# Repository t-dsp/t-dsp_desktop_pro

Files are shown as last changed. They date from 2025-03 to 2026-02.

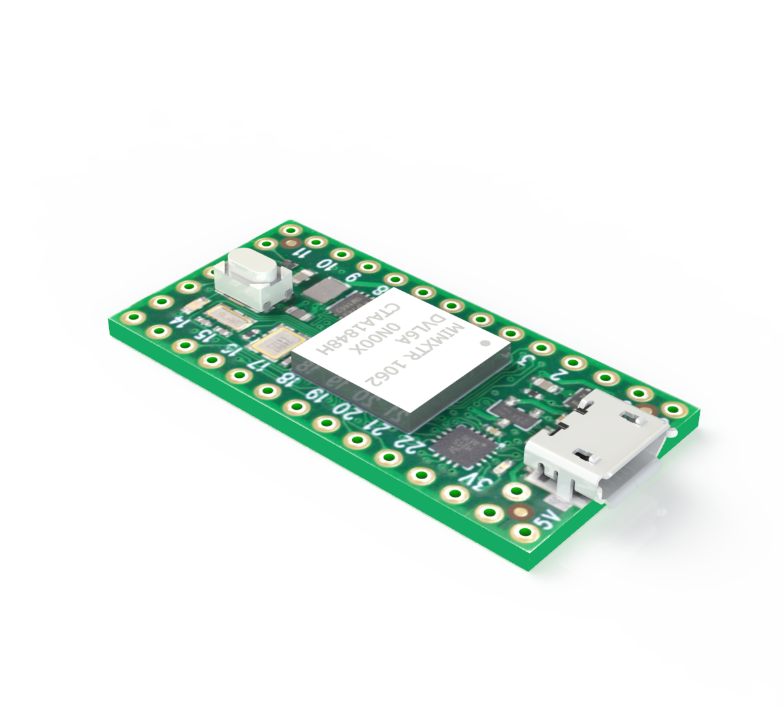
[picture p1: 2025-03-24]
3d_models/teensy-4-0-1.snapshot.3/Teensy_4.0/Renders/Teensy_4.0.png

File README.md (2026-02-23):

# T-DSP Desktop Pro

**Part of the [T-DSP](https://t-dsp.com) open modular audio platform.**

A desktop audio backplane (120mm x 100mm) that serves as the central hub for the T-DSP modular audio ecosystem. Hosts a Teensy 4.1, ESP32, and T-DSP TAC5212 pro audio codec module on an 8-layer PCB designed for studio-quality signal integrity.

T-DSP Desktop Pro - Top Isometric

| | |
|:---:|:---:|
| Top | Bottom |
| Front | Rear |

**[View 3D Render Gallery](https://t-dsp.github.io/t-dsp_desktop_pro/gallery.html)** -- interactive slideshow of all board views

## About T-DSP

T-DSP is an open modular audio platform designed for musicians, engineers, and developers who want powerful digital signal processing in a flexible, hackable format. Built around the [Teensy](https://www.pjrc.com/teensy/) microcontroller and the [Teensy Audio Library](https://www.pjrc.com/teensy/td_libs_Audio.html), T-DSP combines studio-quality audio with a growing library of open-source modules for mixing, synthesis, effects, and more.

Whether you're building a custom digital mixer, crafting a unique instrument, or prototyping audio products, T-DSP gives you the tools to bring your ideas to life.

Join the community, contribute to the library, or grab a module and start patching. Learn more at [t-dsp.com](https://t-dsp.com).

## Overview

The Desktop Pro is a **backplane PCB** that hosts a Teensy 4.1, ESP32, and T-DSP codec module alongside supporting ICs to create a complete audio development platform. It provides all the connectors, processing, networking, and user interface needed to build desktop audio devices.

## Processing

- **Teensy 4.1** -- ARM Cortex-M7 running the Teensy Audio Library for real-time audio processing (mixing, effects, synthesis, routing). Also receives USB Audio.
- **ESP32** -- UI controller, WiFi/Bluetooth connectivity. Runs the display, buttons, and encoder, and sends commands to the Teensy over serial.
- **T-DSP TAC5212 Module** -- Professional stereo audio codec (ADC + DAC) with mic preamp, line, and instrument inputs

## On-Board ICs

| Ref | Part | Function |
|-----|---|---|
| U1 | Teensy 4.1 | Audio DSP (ARM Cortex-M7) |
| U2 | ESP32-DevKitC | UI controller, WiFi/Bluetooth |
| U3 | TPS2116DRL | Power multiplexer (dual input selection) |
| U4 | H11L1SM | Optoisolator (MIDI input) |
| U5-U8 | SN74LVC2G125DCTR | Dual bus buffers (4x) |
| U9 | 74HCT2G17GW | Dual Schmitt trigger buffer |
| U10 | TPD4E02B04DQA | USB ESD protection (4-channel) |
| IC1 | 74HCT2G125DC | Logic level shifter |
| D5 | TPD1E10B06DPYT | VBUS ESD protection |
| Q1, Q2 | DMG2307L-7 | P-FET reverse polarity protection |

## Connectivity

### Audio I/O
- **RCA outputs** -- Stereo analog audio output
- **RCA inputs** -- Stereo analog audio input
- **Headphone output** -- 1/4" (6.35mm) or 3.5mm headphone jack
- **S/PDIF** -- Digital audio input and output

### USB
- **USB-C DEVICE** -- Power and USB Audio to Teensy with ESD protection (TPD4E02B04 + TPD1E10B06)
- **USB-A HOST** -- USB host connector

### MIDI
- **MIDI input** -- 3.5mm TRS with optical isolation (H11L1)
- **MIDI GPIO** -- Configurable for MIDI in, out, or thru

### Power
- **Dual power input** -- USB-C or external supply via JST-XH header, with TPS2116 power multiplexer for automatic switchover
- **Reverse polarity protection** -- P-channel MOSFET (DMG2307L-7) on both 5V and 12V inputs
- **Power indicators** -- LED indicators for 5V and 12V rails

### Storage
- **SD card** -- Accessible via Teensy 4.1 built-in SD slot

## Expansion

- **2x TDM expansion headers** (2x10 pin, 2.54mm) -- Connect T-DSP audio modules
  - TDM digital audio bus (BCLK, LRCK, DATA_IN, DATA_OUT, MCLK)
  - I2C control bus (SDA, SCL)
  - Power rails (3.3V, 5V, 12V, GND)
  - Control pins (Held-high, Held-low)
- Modules can be soldered directly or socketed with pin headers
- Multiple modules can be chained on the same TDM bus

## User Interface

The backplane exposes interface-ready GPIO headers for flexible UI connectivity, supporting popular interface options compatible with the ESP32.

- **GPIO header** -- Active-low buttons, rotary encoder, and display connections for tactile UI
- **OLED display header** (128x64, SSD1306) -- Status and menu-driven UI
- **3.2" TFT touchscreen header** (ILI9341) -- Touchscreen UI
- **SK6812 addressable LED header** -- ESP32 and Teensy status indication, plus LED strip control

## Board Design

- **8-layer PCB** with dedicated ground and power planes for low-noise analog performance
- **120mm x 100mm** board dimensions
- LDO voltage regulation for clean analog power
- Buffered digital outputs for reliable module distribution
- Separate analog and digital ground domains

## Project Files

| Directory | Contents |
|---|---|
| `/3d_models/` | 3D models for PCB components |
| `/documentation/` | [Schematic PDF](documentation/t-dsp-desktop-pro-schematic.pdf), board images, and reference docs |
| `/lib_fp/` | Custom KiCad footprint libraries |
| `/lib_sch/` | Custom KiCad schematic symbol libraries |
| `/manufacturing/` | CI-generated manufacturing outputs (gerbers, BOM, pick & place, PDFs) |
| `/panel/` | Panelized board layouts for production |
| `/pages/` | [3D Render Gallery](https://t-dsp.github.io/t-dsp_desktop_pro/gallery.html), [Interactive BOM](https://t-dsp.github.io/t-dsp_desktop_pro/ibom.html) |

View the design files directly in your browser with KiCanvas: [Schematic](https://kicanvas.org/?github=https://github.com/t-dsp/t-dsp_desktop_pro/blob/main/t-dsp_desktop_pro.kicad_sch) | [PCB](https://kicanvas.org/?github=https://github.com/t-dsp/t-dsp_desktop_pro/blob/main/t-dsp_desktop_pro.kicad_pcb)

## Status

This board is under active development. The current revision includes USB-C ESD protection, reverse polarity protection, and boot pin corrections from the pre-production review.

If you build one, we'd love to hear how it goes -- please open an issue or reach out with your findings.

## Contact

For consulting, custom backplane design, or commercial licensing inquiries, reach out via [LinkedIn](https://linkedin.com/in/jayshoe).

## License

This project is licensed under the [Creative Commons Attribution-NonCommercial-ShareAlike 4.0 International (CC BY-NC-SA 4.0)](https://creativecommons.org/licenses/by-nc-sa/4.0/).

You are free to share and adapt this work for non-commercial purposes, as long as you give appropriate credit and distribute any derivatives under the same license.

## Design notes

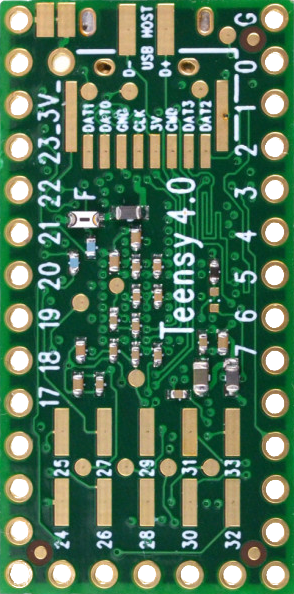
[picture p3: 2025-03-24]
3d_models/teensy-4-0-1.snapshot.3/Teensy_4.0/Teensy_4.0_Decal/Teensy_4.0_Back.png

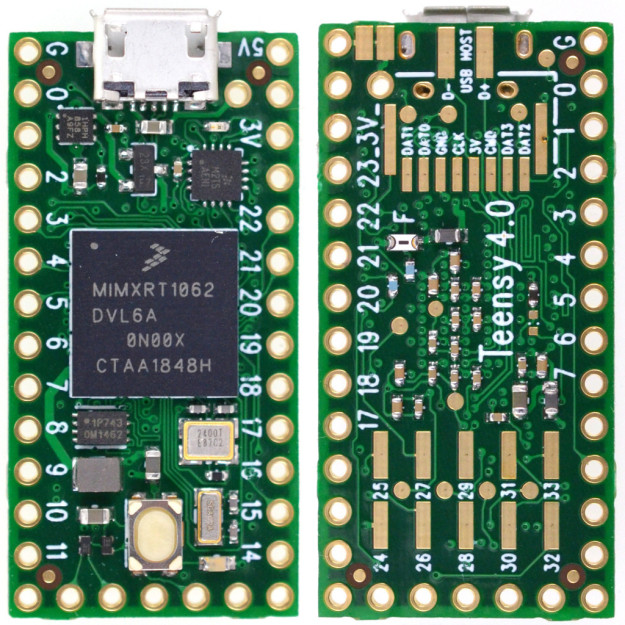
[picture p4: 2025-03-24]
3d_models/teensy-4-0-1.snapshot.3/Teensy_4.0/Teensy_4.0_Decal/teensy40-launch-frontandback-thumb.jpg

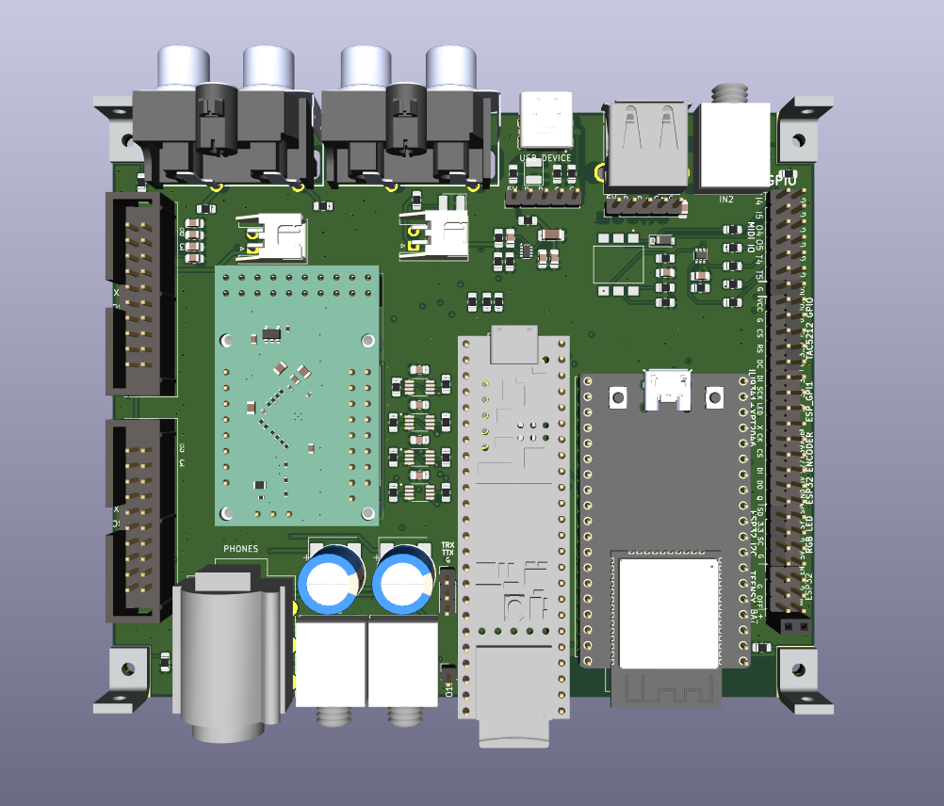
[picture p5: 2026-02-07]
documentation/t-dsp-desktop-pro-3d-top.png

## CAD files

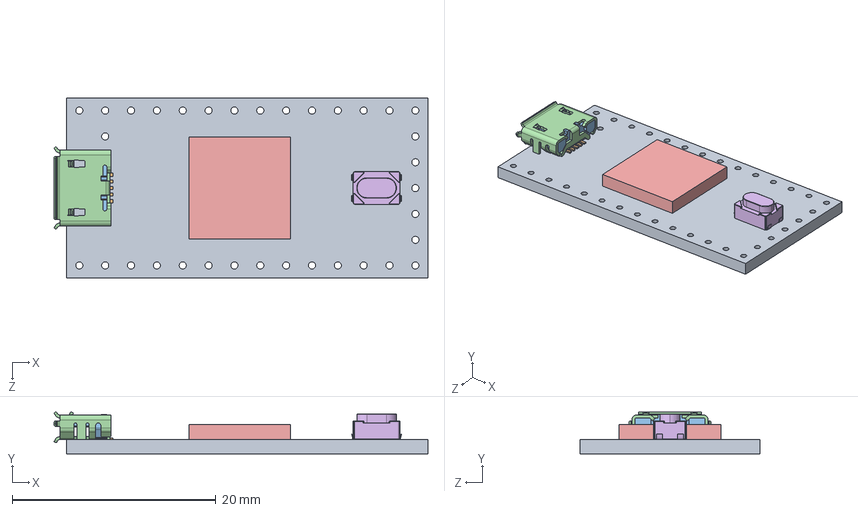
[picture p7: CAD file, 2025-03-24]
3d_models/teensy-4-0-1.snapshot.3/Teensy_4.0/Teensy_4.0_Assembly.STEP
36.8 x 4.12 x 17.7 mm
Teensy_4.0_PCB
Micro USB-B Female 5Pin SMD
NXP iMXRT1062
SKRPACE010 v4

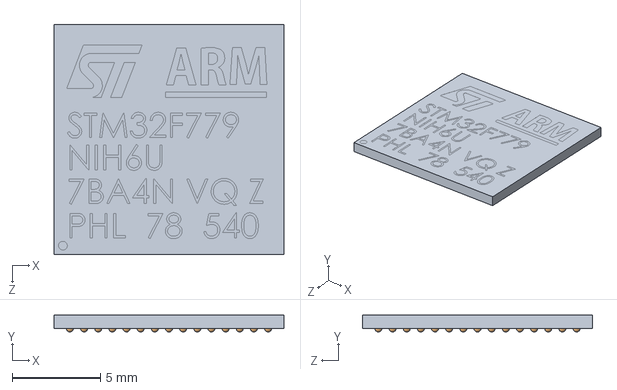
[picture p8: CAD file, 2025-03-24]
3d_models/teensy-4-0-1.snapshot.3/Teensy_4.0/STM32F779NIHx.SLDASM
13.0 x 0.96 x 13.0 mm
ball x 216

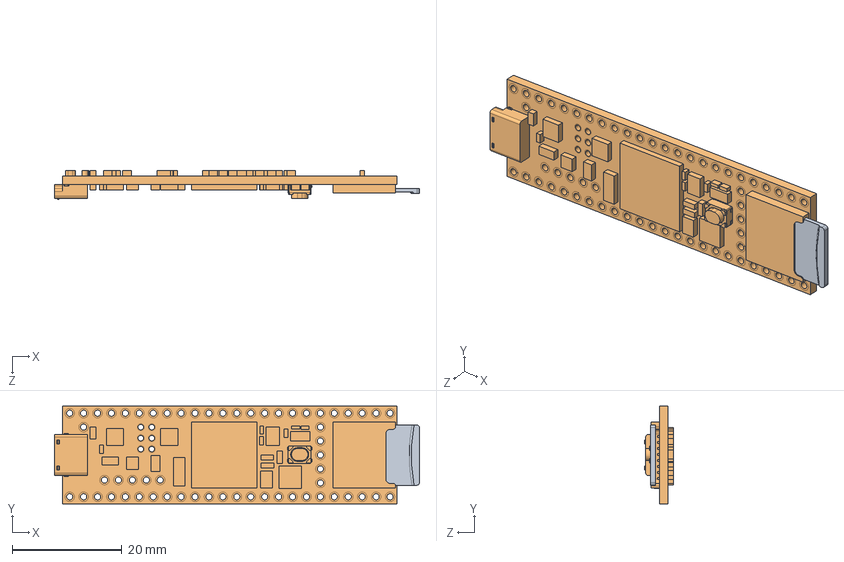
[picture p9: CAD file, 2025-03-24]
3d_models/Teensy_4.1_Assembly.STEP
66.6 x 17.8 x 5.27 mm

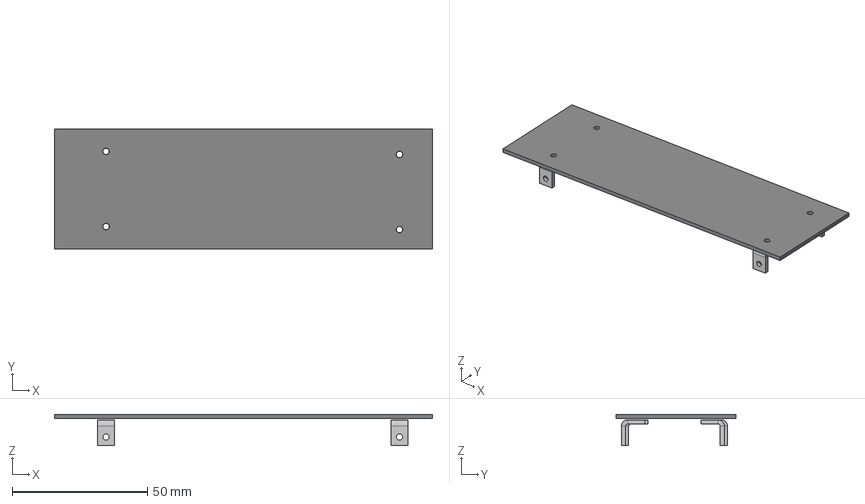
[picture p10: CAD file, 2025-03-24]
3d_models/audio_project_board_step/teensy41_audio_project_board_end2.step
139.7 x 44.5 x 11.5 mm
Pcb_76c7
H3_Bracket 4-40 621_9e0d8cd628db x 4

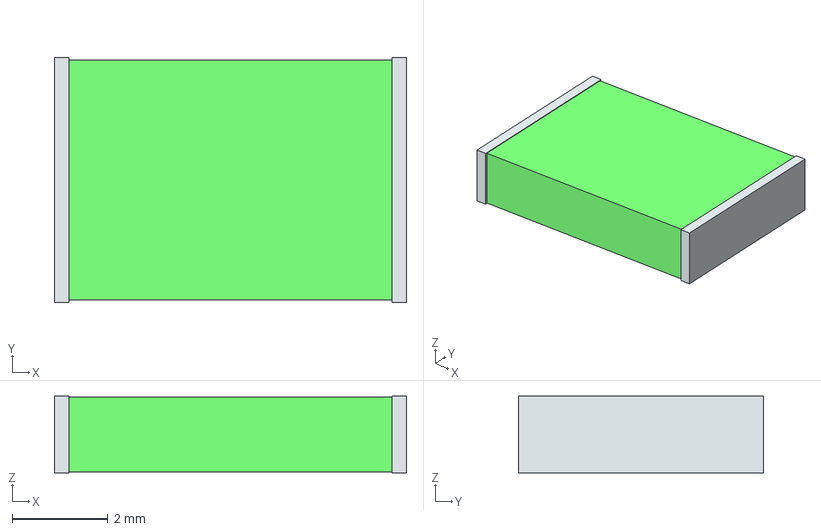
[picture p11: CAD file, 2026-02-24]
3d_models/MF-LSMF300_24X-2.stp
7.36 x 5.12 x 1.60 mm
term1
term2

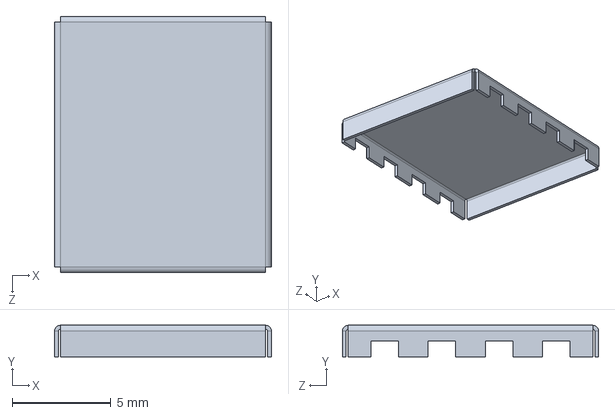
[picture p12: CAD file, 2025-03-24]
3d_models/raspberry-pi-4-model-b-1.snapshot.3/Cypress CYW43455 Wireless Module Cover, RPi4ModelB.SLDPRT
11.0 x 1.60 x 13.0 mm

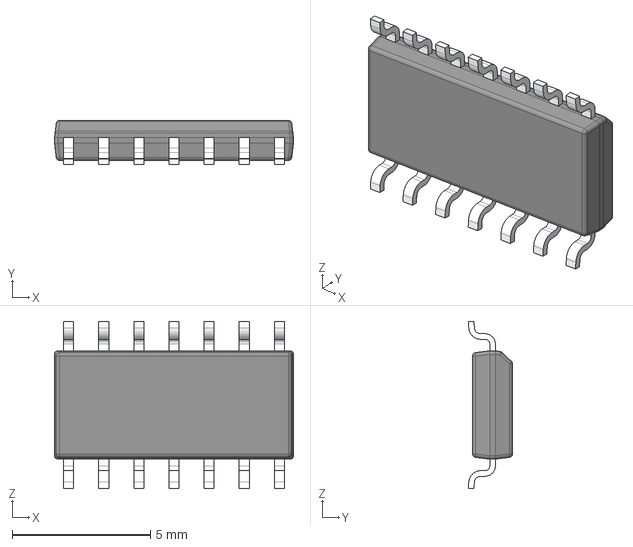
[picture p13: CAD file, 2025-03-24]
3d_models/so-14-soic14-1.snapshot.2/soic-14.stp
8.64 x 1.60 x 6.05 mm
BODY_M14A_20
LEAD_M14A_46 x 14

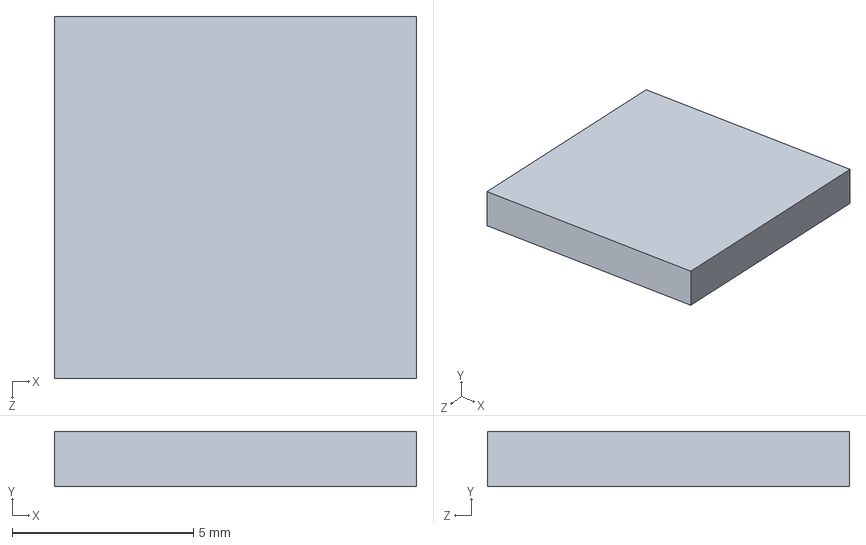
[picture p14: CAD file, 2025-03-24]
3d_models/teensy-4-0-1.snapshot.3/Teensy_4.0/NXP iMXRT1062.SLDPRT
10.0 x 1.52 x 10.0 mm

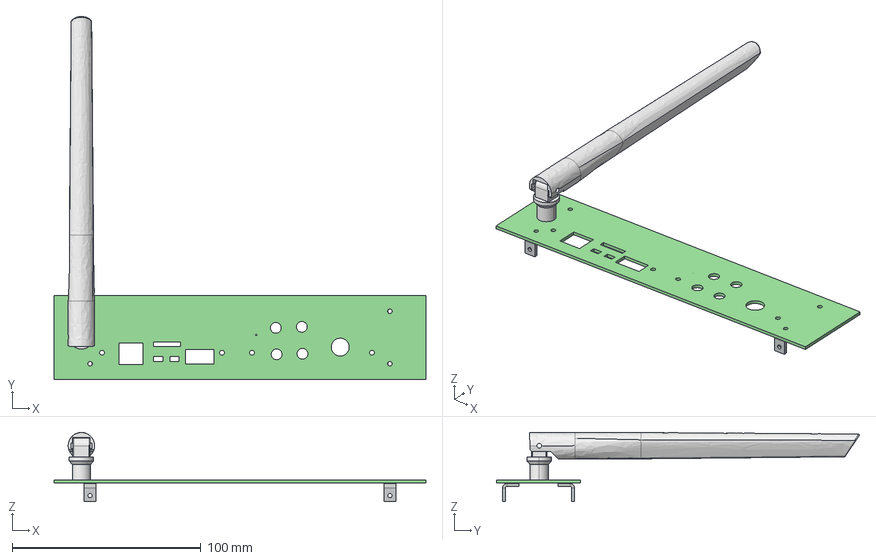
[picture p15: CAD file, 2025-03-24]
3d_models/audio_project_board_step/teensy41_audio_project_board_fp_c_front.step
196.8 x 192.2 x 36.6 mm
front_panel PCB

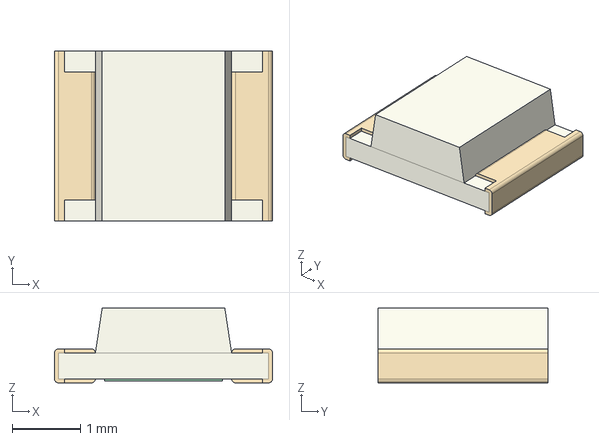
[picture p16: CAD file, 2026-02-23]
3d_models/LED_1210_3225Metric.step
3.20 x 2.50 x 1.10 mm

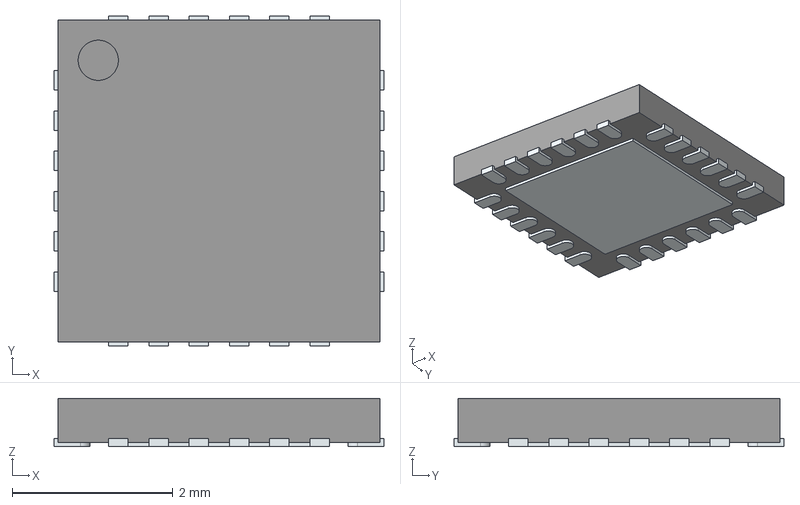
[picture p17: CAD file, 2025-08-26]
lib_fp/project_fp/CYPD3177-24LQXQ.stp
4.10 x 4.10 x 0.6 mm
ThermalPin
PinsArrayLR
PinsArrayTB

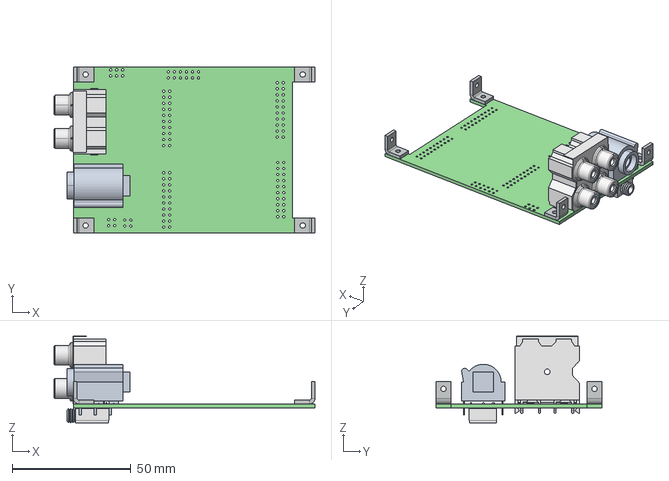
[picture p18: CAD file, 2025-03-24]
3d_models/audio_project_board_step/teensy41_audio_project_board_codec.step
109.8 x 69.8 x 36.5 mm
_autosave-teensy41_audio_project_board PCB

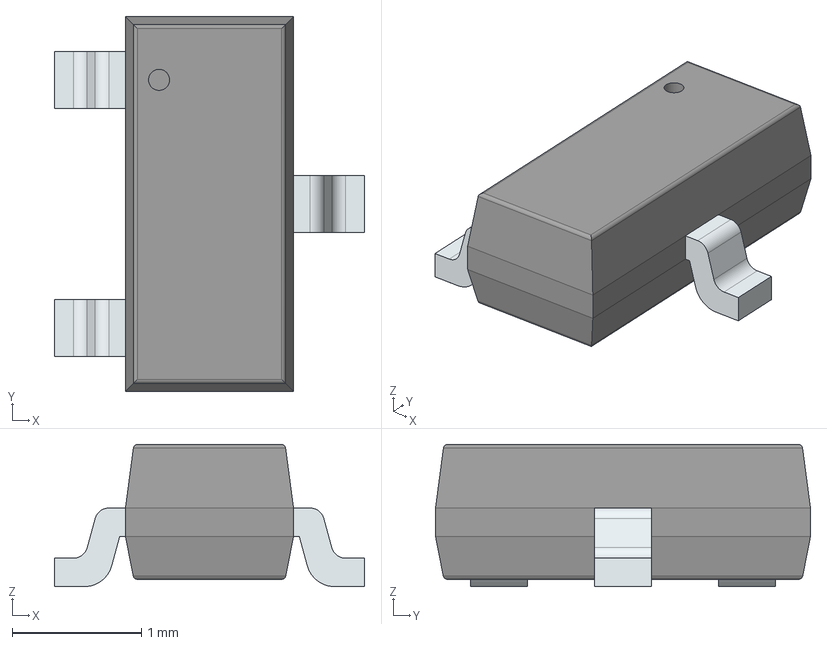
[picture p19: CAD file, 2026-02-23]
3d_models/DMG2307L-7.stp
2.40 x 2.90 x 1.10 mm
PinsArrayL
FilletPinR

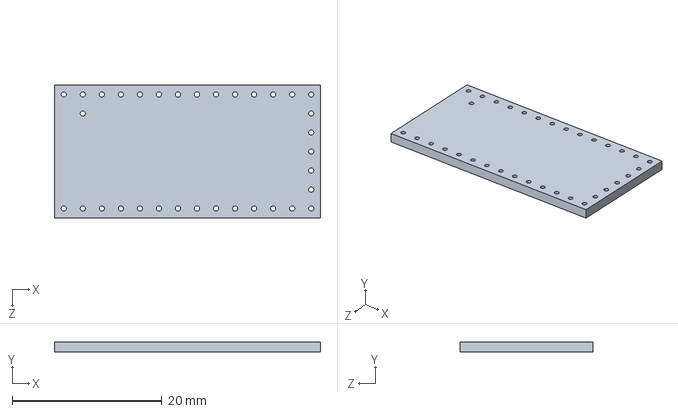
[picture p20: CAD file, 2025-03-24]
3d_models/teensy-4-0-1.snapshot.3/Teensy_4.0/Teensy_4.0_PCB.SLDPRT
35.5 x 1.40 x 17.7 mm

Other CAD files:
lib_fp/project_fp/TYPE-C-31-M-12.step
3d_models/1808--3DModel-STEP-630548.STEP
3d_models/2120--3DModel-STEP-630548.STEP
3d_models/3-D NC3MAH.stp
3d_models/3-D NCJ6FAH.stp
3d_models/3-D NCJ6FI-H-0.stp
3d_models/3-d-nmj6hcd3.stp
3d_models/3.5MM_STEREO_35RAPC4BHN2.STEP
3d_models/35RAPC3BH3.STEP
3d_models/35RAPC7JS.STEP
3d_models/35RAPC7JS_SIMPLIFIED.step
3d_models/3_2SPI-TFT-Modul_ILI9341.STEP
3d_models/4691.step
3d_models/74HCT2G125DC,125.stp
3d_models/74LS00.step
3d_models/Bracket 4-40 621.STEP
3d_models/COMBO-NCJ6FA-H.step
3d_models/COMBO_XLR_NCJ6FI-H-0.stp
3d_models/CP_Radial_D10.0mm_P5.00mm.step
3d_models/C_1206_3216Metric.step
3d_models/DC_BARREL_PJ-202AH.step
3d_models/DIN-5.STEP
3d_models/D_1210_3225Metric.step
3d_models/EN11-HSM1AF15.STEP
3d_models/ESP32 WROOMU.step
3d_models/ESP32-DEVKITC-32D.step
3d_models/ESP32-WROOM-32E.STEP
3d_models/ESP32-WROOM-32E_No-Cover.STEP
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

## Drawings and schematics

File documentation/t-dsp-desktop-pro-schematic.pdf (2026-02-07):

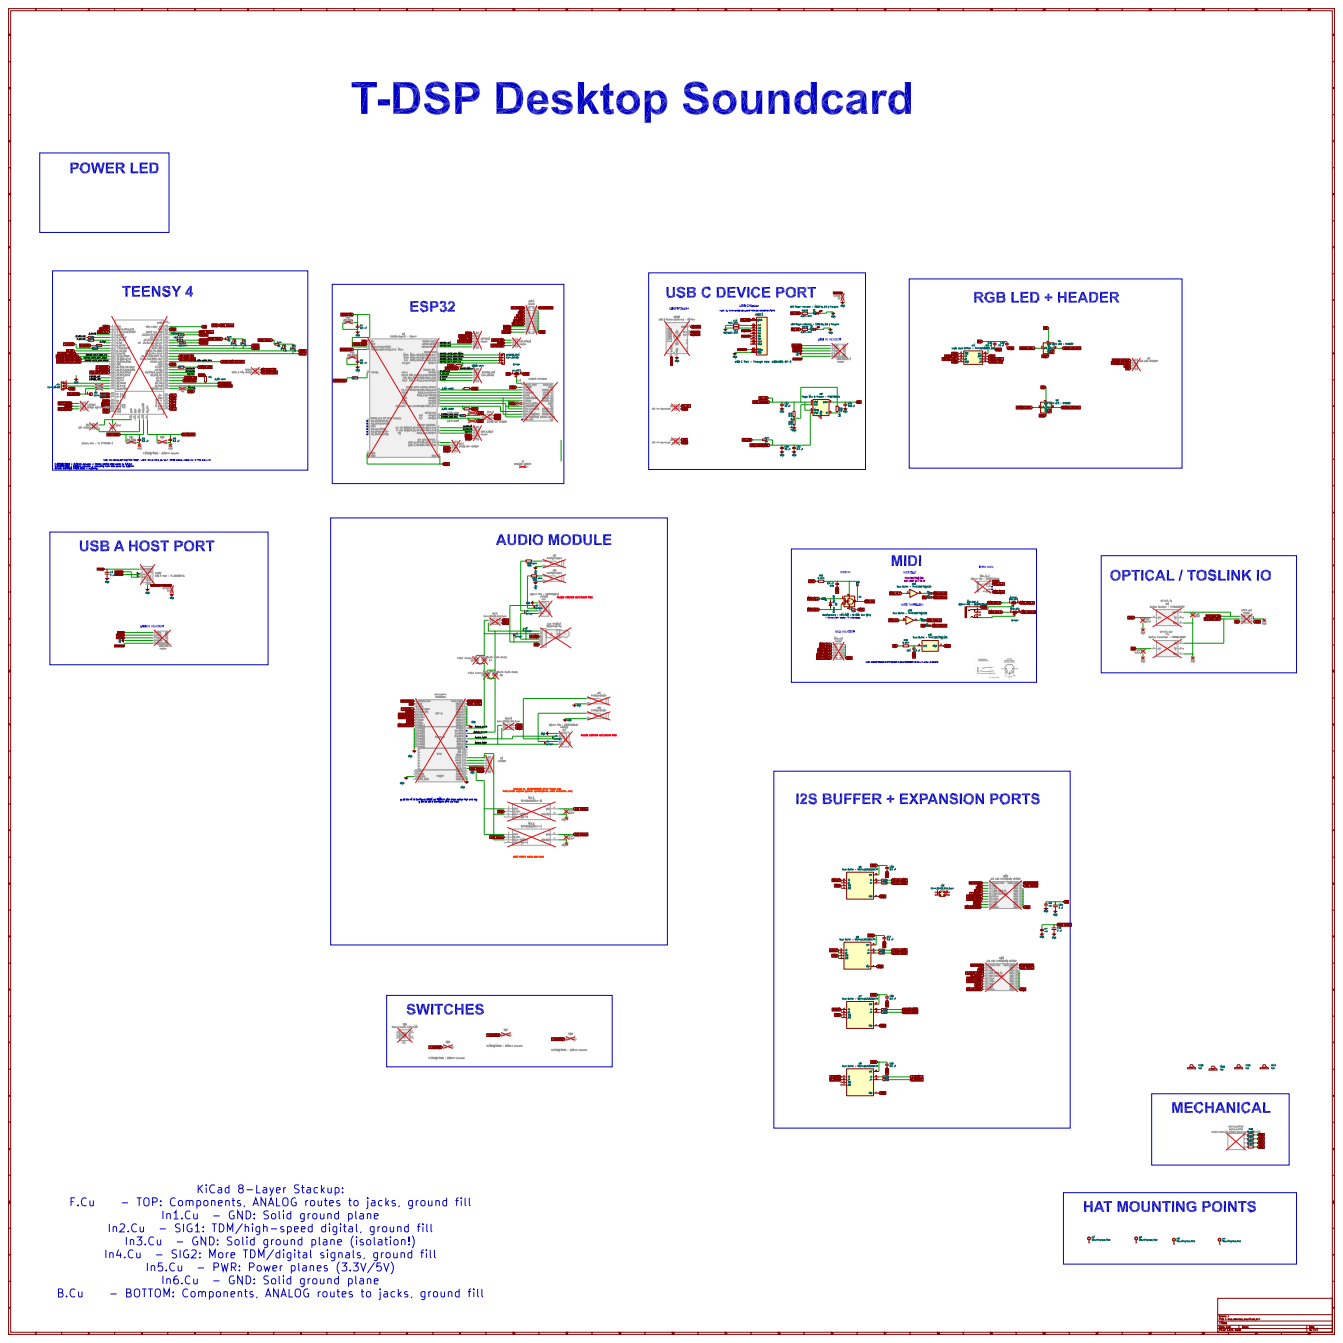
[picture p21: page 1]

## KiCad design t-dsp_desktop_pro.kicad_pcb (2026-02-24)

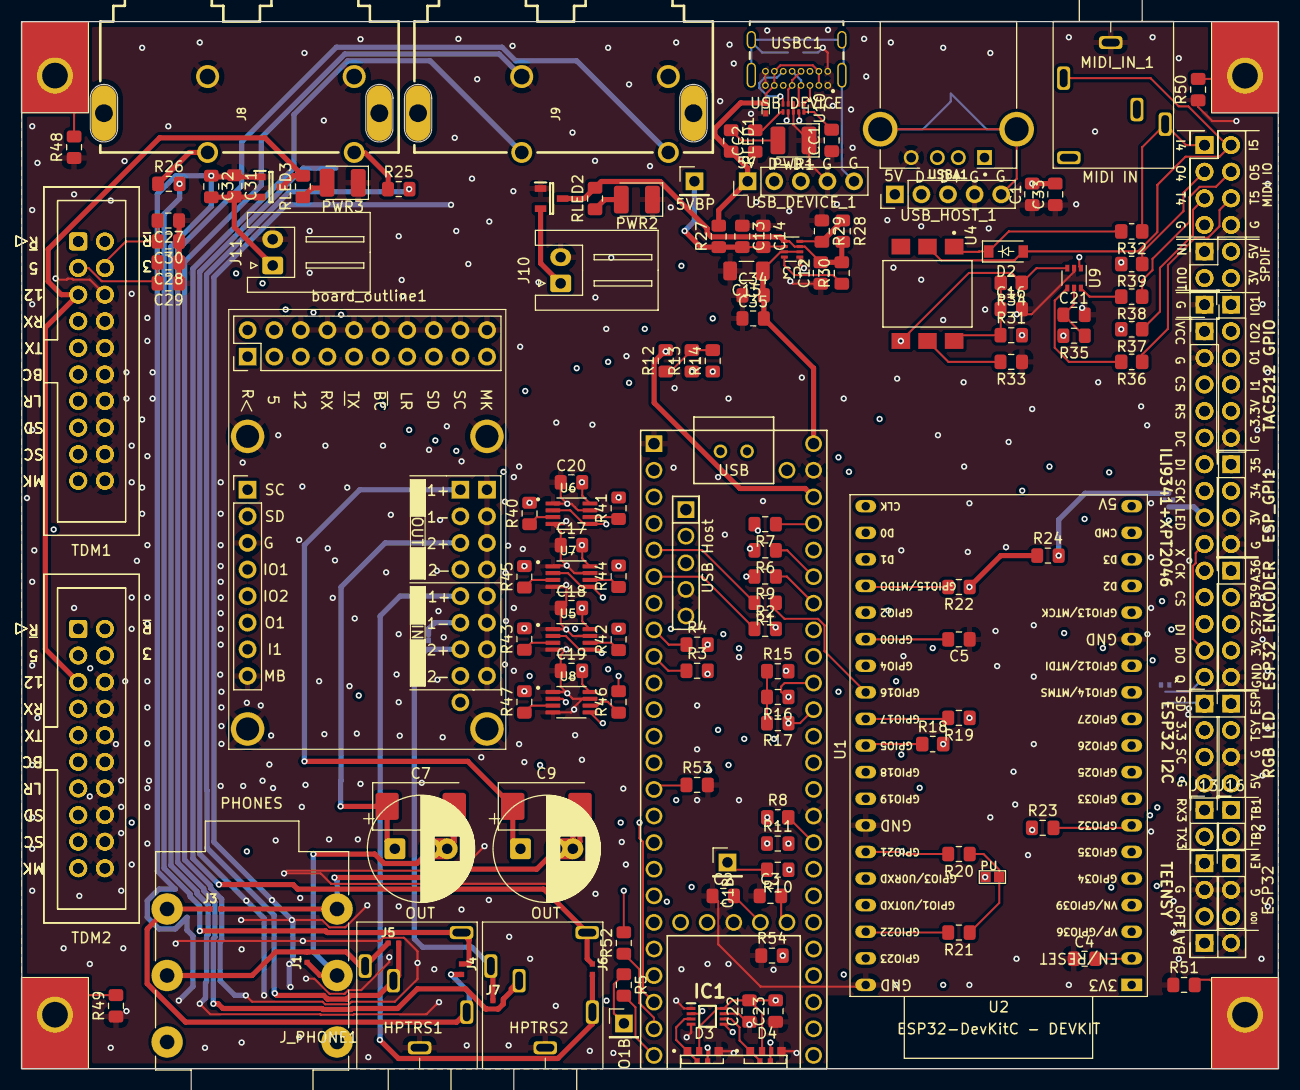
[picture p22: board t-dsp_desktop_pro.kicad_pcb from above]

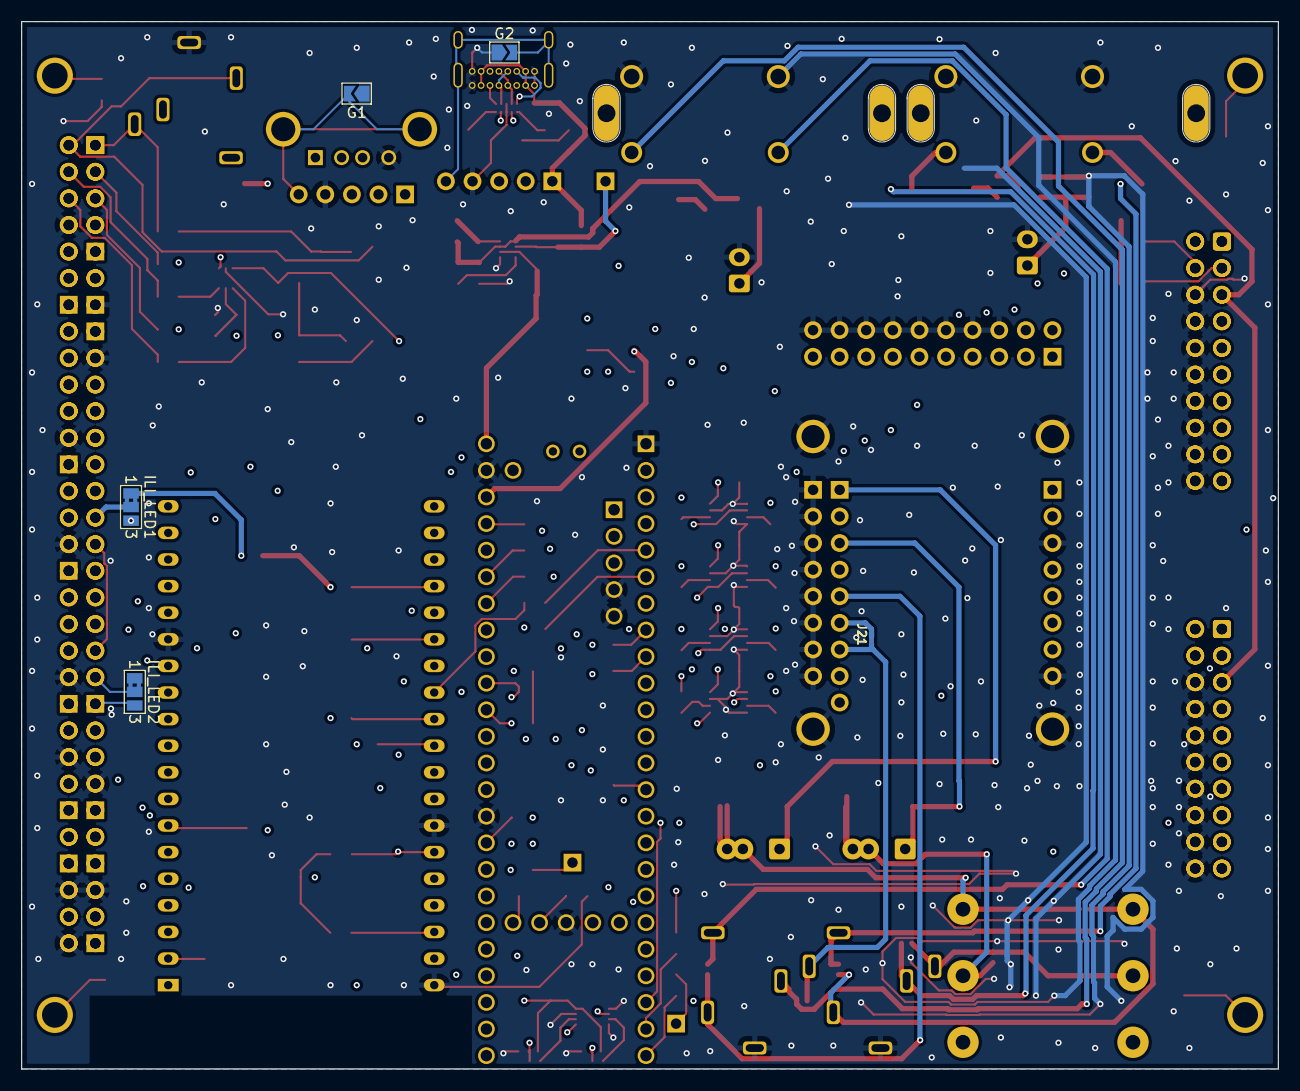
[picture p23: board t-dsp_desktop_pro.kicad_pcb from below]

Board: 8 copper layers, 120.0 x 100.0 mm, 156 parts (5 on the bottom side), 154 nets.

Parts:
BAT1: BAT HEADER; PinHeader_1x02_P2.54mm_Vertical_BAT
C1, C29, C30: 1 uF; C_0805_2012Metric_Pad1.15x1.40mm_HandSolder
C2, C3, C4, C5, C14, C16, C17, C18, C19, C20, C21, C22, C32, C35: 0.1 uF; C_0805_2012Metric_Pad1.15x1.40mm_HandSolder
C7, C9: 470 uF Electrolytic Audio-Grade; CP_Radial_D10.0mm_P5.00mm_AND_D8.0mm_P3.5mm
C12, C13, C23, C31, C33, C34: 10 uF; C_0805_2012Metric_Pad1.15x1.40mm_HandSolder
C15: 100 uF; C_1206_3216Metric_Pad1.33x1.80mm_HandSolder
C27, C28: 47uF; C_0805_2012Metric_Pad1.15x1.40mm_HandSolder
CC1, CC2: 5.1k ohm; R_0805_2012Metric_Pad1.15x1.40mm_HandSolder
D1: HEADER; TAC5212 GPIO_PinHeader_1x06_P2.54mm_Vertical
D2: Diode - 1N4148; D_SOD-123
D3, D4: Side Light LED - SK6812; SK6812-32228SMD-Reverse-Mount_mod
D5: TPD1E10B06DPYT
ESP_I1: ESP32 I2C HEADER; ESP_I2C_PinHeader_1x04_P2.54mm_Vertical
ESP_PROG1: header; E_PROG1_PinHeader_1x03_P2.54mm_Vertical
ESP_R_ENC1: header; ESP_R_ENC0_PinHeader_1x05_P2.54mm_Vertical
G1, G2: jumper; SolderJumper-2_P1.3mm_Open_TrianglePad1.0x1.5mm
GPI1: ESP32 GPI HEADER; GPI1_PinHeader_1x04_P2.54mm_Vertical
HPTRS1, HPTRS2: 3.5mm TRS - 35RAPC3BH3; 35RAPC3BH3
IC1: Logic Level Shifter - 74HCT2G125DC,125; SOP50P310X100-8N
ILI1: ILI9341+XPT2046; ILI9341_PinHeader_1x14_P2.54mm_Vertical
ILI_LED1, ILI_LED2: jumper; SolderJumper-3_P1.3mm_Bridged2Bar12_Pad1.0x1.5mm_NumberLabe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
J1, J3, J4, J5, J6, J7: jumper; jumper_slice_disconnected
J2: GROUND HEADER; GPIO_GROUND_PinHeader_1x01_P2.54mm_Vertical
J8, J9: PJRAS2X1S01X; PJRAS2X1S01X_MOD2
J10, J11: JST-XH Connector; JST_XH_S2B-XH-A_1x02_P2.50mm_Horizontal
J12: RGB LED HEADEER; LED_GPIO_PinHeader_1x04_P2.54mm_Vertical
J13: Conn_01x02; T_SERIAL_PinHeader_1x02_P2.54mm_Vertical_NO_CTYD
J15, J19: Conn_01x01; OUT1B_PinHeader_1x01_P2.54mm_Vertical
J16: Conn_01x02; T_BUTTON_PinHeader_1x02_P2.54mm_Vertical_NO_CTYD
J17: Conn_02x04_Odd_Even; PinHeader_2x04_P2.54mm_Vertical_MIDI_IO
J18: Conn_02x02_Odd_Even; PinHeader_2x02_P2.54mm_Vertical_SPDIF_IO
J20: Conn_01x01; USB_5V_PinHeader_1x01_P2.54mm_Vertical
J21: jumper; jumper_slice
J_PHONE1: NMJ6HFD2-AU; Jack_6.35mm_Neutrik_NMJ6HCD3_Horizontal
MIDI_IN_1: 3.5mm TRS - 35RAPC3BH3; 35RAPC3BH3
PU_EN108: JUMPER; SolderJumper-2_Open_Pad0.5x1.0mm_PU
PWR1, PWR2, PWR3: LED Power Indicator - 1206 5v 2.0 V Forward; LED_1210_3225Metric_Pad1.42x2.65mm_HandSolder
Q1, Q2: DMG2307L-7
R1, R2, R3, R4, R5, R6, R7, R9, R10, R24, R25, R26, R40, R41, R42, R43, R44, R45, R46, R47, R52: 49.9 ohm; R_0805_2012Metric_Pad1.15x1.40mm_HandSolder
R8, R18, R32, R34, R36, R37, R38, R39: 220 ohm; R_0805_2012Metric_Pad1.20x1.40mm_HandSolder
R11, R19, R22, R23, R53, R54: 10k; R_0805_2012Metric_Pad1.15x1.40mm_HandSolder
R12, R15, R27, R31, R35, R48, R49, R50, R51: 0 ohm; R_0805_2012Metric_Pad1.15x1.40mm_HandSolder
R13, R14, R16, R17, R20, R21: 2.21k ohm; R_0805_2012Metric_Pad1.15x1.40mm_HandSolder
R28: 16.9k ohm; R_0805_2012Metric_Pad1.15x1.40mm_HandSolder
R29, R30: 5.1k ohm; R_0805_2012Metric_Pad1.15x1.40mm_HandSolder
R33: 1.5k ohm; R_0805_2012Metric_Pad1.15x1.40mm_HandSolder
RLED1, RLED2: 1k; R_0805_2012Metric_Pad1.15x1.40mm_HandSolder
RLED3: 6.8K; R_0805_2012Metric_Pad1.15x1.40mm_HandSolder
T108, T109, T110, T111: Tab
TDM1, TDM2: T-DSP_expansion_header; T-DSP_Expansion_Header_2x10_ALT_GND
T_PROG1: TEENSY SWITCH HEADER; T_PROG1_PinHeader_1x03_P2.54mm_Vertical
U1: Teensy 4.1 - DEVKIT; Teensy41_mod3
U2: ESP32-DevKitC - DEVKIT; ESP32-DevKitC_NO_COURTYARD
U3: Power Mux & Protect - TPS2116DRL; TPS2116DRL
U4: Optoisolators - H11L1SM - 6-SMD, Gull Wing; IC_H11L1SM
U5, U6, U7, U8: Dual Buffer - SN74LVC2G125DCTR; SOP65P400X130-8N
U9: Dual Buffer - 74HCT2G17GW,125; SOT-363_SC-70-6
U10: TPD4E02B04DQA
USBA1: USB A Host - TE 292303-5; TE_292303-5_USB_A
USBC1: USB C Port - Through Hole USB4085-GF-A; GCT_USB4085-GF-A_REVA4
USB_DEVICE_1: header; USB_IN1
USB_HOST_1: header; USB_IN1
board_outline1: TAC5212 Module; audio_module_board_outline_50x34.5_d1
board_outline2: board_outline; audio_project_board_outline_100x120

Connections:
2_OUT2: U1.4 (2_OUT2), U2.8 (32K_XN/GPIO33/ADC1_CH5)
3.3V: C17.1, C18.1, C19.1, C20.1, C27.1, C30.1, D1.5, ESP_I1.2, ESP_R_ENC1.4, GPI1.3, J18.4, PU_EN108.1, R11.1, R12.2, R15.2, R19.1, R22.1, R23.1, R24.1, R31.2, TDM1.4 (3.3V), TDM2.4 (3.3V), U1.46 (3V3), U5.8 (VCC), U6.8 (VCC), U7.8 (VCC), U8.8 (VCC), board_outline1.4 (3.3V), board_outline2.12 (3V), board_outline2.22 (3.3), board_outline2.30 (3V), board_outline2.40 (3V), board_outline2.45 (3.3), board_outline2.T4 (3.3V), board_outline2.TT4 (Pin_4)
3_LRCLK2: R1.1, U2.27 (GPIO16)
4_BCLK2: R2.2, U2.10 (DAC_2/ADC2_CH9/GPIO26)
5V: C15.1, C22.1, C23.1, C28.1, C29.1, C34.1, C35.1, D3.2 (VDD), D4.2 (VDD), IC1.8 (VCC), ILI1.1 (VCC_(5V)), J12.4, J18.2, R35.2, R37.2, R39.2, TDM1.3 (5V), TDM2.3 (5V), U1.48 (VIN), U2.19 (5V), U3.2 (VOUT), U3.7 (VOUT), board_outline1.3 (5V), board_outline2.10 (5V), board_outline2.15 (VCC), board_outline2.50 (5V), board_outline2.T3 (5V), board_outline2.TT3 (Pin_3)
5V_JST: C12.1, Q1.3 (D), R28.2, R30.2, RLED2.2, U3.3 (VIN1), U3.5 (MODE)
5V_USB: D5.1, R27.2, RLED1.2, USBC1.A4 (VBUS), USBC1.A9 (VBUS), USBC1.B4 (VBUS), USBC1.B9 (VBUS), USB_DEVICE_1.1 (5V)
5_IN2: U1.7 (5_IN2), U2.9 (DAC_1/ADC2_CH8/GPIO25)
6_OUT1D: R4.2, U8.5 (2A)
6_OUT1D+: R47.2, TDM2.9 (DSP_DATA_OUT), board_outline2.TT9 (Pin_9)
7_OUT1A: R3.2, U8.2 (1A)
7_OUT1A+: R46.2, TDM1.9 (DSP_DATA_OUT), board_outline1.7 (DSP_DOUT), board_outline2.T9 (DSP_DATA_OUT)
8_IN1: TDM1.7 (DSP_DATA_IN), U1.10 (8_TX2_IN1), board_outline1.9 (DSP_DIN), board_outline2.T7 (DSP_DATA_IN)
9_OUT1C_INPUT: TDM2.7 (DSP_DATA_IN), U1.11 (9_OUT1C), board_outline2.TT7 (Pin_7)
12V: Q2.3 (D), RLED3.2, TDM1.5 (12V), TDM2.5 (12V), board_outline2.T5 (12V), board_outline2.TT5 (Pin_5)
14_SPDIF_OUT: J18.3, U1.36 (14_A0_TX3_SPDIF_OUT), board_outline2.11 (OUT)
15_SPDIF_IN: J18.1, U1.37 (15_A1_RX3_SPDIF_IN), board_outline2.9 (IN)
32_OUT1B: J15.1, R5.1
34_RX8_RESET2: R54.2, TDM1.2 (HELD_LOW), TDM2.2 (HELD_LOW), U1.26 (34_RX8), board_outline1.2 (HELD_LOW), board_outline2.T2 (HELD_LOW), board_outline2.TT2 (Pin_2)
35_TX8_RESET: R11.2, TDM1.1 (HELD_HIGH), TDM2.1 (HELD_HIGH), U1.27 (35_TX8), board_outline1.1 (HELD_HIGH), board_outline2.T1 (HELD_HIGH), board_outline2.TT1 (Pin_1)
53_T_PROG: C2.1, T_PROG1.1, U1.53 (PROGRAM), board_outline2.55 (?)
54_ON_OFF: C3.1, T_PROG1.3, U1.54 (ON_OFF), board_outline2.59 (OFF)
/AUDIO_IN1P: HPTRS2.5, J6.1, board_outline1.29 (IN1P)
/AUDIO_IN2P: HPTRS2.2, J7.2, J21.1, board_outline1.33 (IN2P)
/AUDIO_OUT2P: C7.1, board_outline1.25 (OUT2P)
/AUDIO_OUTP: C9.1, board_outline1.21 (OUTP)
/ESP32_IO1: U1.20 (28_RX7), U2.35 (U0TXD/GPIO1)
/ESP32_IO3: U1.21 (29_TX7), U2.34 (U0RXD/GPIO3)
BCLK1: R6.2, U7.2 (1A), U7.5 (2A)
BCLK1+TDM1: R44.2, TDM1.11 (BCLK), board_outline1.11 (BCLK), board_outline2.T11 (BCLK)
BCLK1+TDM2: R45.2, TDM2.11 (BCLK), board_outline2.TT11 (Pin_11)
CRX3: J13.1, U1.22 (30_CRX3), board_outline2.51 (?)
CS: ILI1.3 (CS), R22.2, U2.23 (*MTDO/GPIO15/ADC2_CH3), board_outline2.19 (CS)
DC: ILI1.5 (DC), U2.24 (ADC2_CH2/*GPIO2), board_outline2.23 (DC)
DEVICE_D1+: U1.67 (D+), U10.9 (NC), USB_DEVICE_1.3 (D1+)
DEVICE_D1-: U1.66 (D-), U10.7 (NC), USB_DEVICE_1.2 (D1-)
ESP32_EN: C4.1, ESP_PROG1.1, U1.29 (37_CS), U2.2 (EN/CHIP_PU/RESET), board_outline2.56 (EN)
ESP32_IO0: C5.1, ESP_PROG1.3, U1.28 (36_CS), U2.25 (*GPIO0/BOOT/ADC2_CH1), board_outline2.60 (IOO)
ESP32_IO12_SPI_MISO: R53.1, U1.14 (12_MISO_MQSL), U2.13 (*MTDI/GPIO12/ADC2_CH5)
ESP32_IO13_SPI_MOSI: U1.13 (11_MOSI_CTX1), U2.15 (MTCK/GPIO13/ADC2_CH4)
ESP32_IO14_SPI_SCK: U1.35 (13_SCK_LED), U2.12 (MTMS/GPIO14/ADC2_CH6)
ESP32_IO21_SDA: ESP_I1.1, ILI_LED2.3 (B), R20.2, U2.33 (GPIO21), board_outline2.43 (SD)
ESP32_IO22_SCL: ESP_I1.3, ILI_LED1.3 (B), R21.2, U2.36 (GPIO22), board_outline2.47 (SC)
ESP32_IO33_SPI_CS: R19.2, U1.12 (10_CS_MQSR), U2.28 (GPIO17)
ESP32_LED: IC1.2 (1A), R18.2
ESP32_LED+: D4.1 (DIN), IC1.6 (1Y)
ESP32_LED_OUT: D4.3 (DOUT), J12.1, board_outline2.44 (ESP)
GND: BAT1.2, C1.2, C2.2, C3.2, C4.2, C5.2, C12.2, C13.2, C14.2, C15.2, C16.1, C17.2, C18.2, C19.2, C20.2, C21.1, C22.2, C23.2, C27.2, C28.2, C29.2, C30.2, C31.2, C32.2, C33.2, C34.2, C35.2, CC1.1, CC2.1, D1.6, D3.4 (GND), D4.4 (GND), D5.2, ESP_I1.4, ESP_PROG1.2, ESP_R_ENC1.5, G1.1, G2.1, GPI1.4, HPTRS1.1, HPTRS2.1, IC1.1 (~1OE), IC1.4 (GND), IC1.7 (~2OE), ILI1.2 (GND), J2.1, J8.S1, J8.S2, J9.S1, J9.S2, J10.2, J11.2, J12.3, J17.7, J17.8, MIDI_IN_1.1, PWR1.1 (K), PWR2.1 (K), PWR3.1 (K), Q1.1 (G), Q2.1 (G), R29.1, R33.1, R48.1, R49.1, R50.1, R51.1, R53.2, R54.1, TDM1.6 (GND), TDM1.8 (GND), TDM1.10 (GND), TDM1.12 (GND), TDM1.14 (GND), TDM1.16 (GND), TDM1.18 (GND), TDM1.20 (GND), TDM2.6 (GND), TDM2.8 (GND), TDM2.10 (GND), TDM2.12 (GND), TDM2.14 (GND), TDM2.16 (GND), TDM2.18 (GND), TDM2.20 (GND), T_PROG1.2, U1.1 (GND), U1.34 (GND), U1.47 (GND), U1.52 (GND), U1.58 (GND), U1.59 (GND), U2.14 (GND), U2.32 (GND), U2.38 (GND), U3.1 (GND), U5.1 (~1OE), U5.4 (GND), U5.7 (~2OE), U6.1 (~1OE), U6.4 (GND), U6.7 (~2OE), U7.1 (~1OE), U7.4 (GND), U7.7 (~2OE), U8.1 (~1OE), U8.4 (GND), U8.7 (~2OE), U9.2 (GND), U10.3 (G), U10.8 (G), USBA1.4 (GND), USBC1.A1 (GND), USBC1.A12 (GND), USBC1.B1 (GND), USBC1.B12 (GND), USB_DEVICE_1.4 (GND), USB_HOST_1.4 (GND), board_outline1.6 (GNDD), board_outline1.8 (GNDD), board_outline1.10 (GNDD), board_outline1.12 (GNDD), board_outline1.14 (GNDD), board_outline1.16 (GNDD), board_outline1.18 (GNDD), board_outline1.20 (GNDD), board_outline1.22 (AGND), board_outline1.24 (AGND), board_outline1.26 (AGND), board_outline1.28 (AGND), board_outline1.30 (AGND), board_outline1.32 (AGND), board_outline1.34 (AGND), board_outline1.36 (AGND), board_outline1.39 (GNDD), board_outline1.44 (GNDD), board_outline1.49 (AGND), board_outline1.50 (AGND), board_outline1.51 (DGND), board_outline1.52 (DGND), board_outline2.7 (G), board_outline2.8 (G), board_outline2.13 (G), board_outline2.17 (G), board_outline2.24 (G), board_outline2.32 (G), board_outline2.42 (GND), board_outline2.48 (G), board_outline2.49 (G), board_outline2.57 (G), board_outline2.58 (G), board_outline2.62 (BAT), board_outline2.T6 (GND), board_outline2.T8 (GND), board_outline2.T10 (GND), board_outline2.T12 (GND), board_outline2.T14 (GND), board_outline2.T16 (GND), board_outline2.T18 (GND), board_outline2.T20 (GND), board_outline2.TT6 (Pin_6), board_outline2.TT8 (Pin_8), board_outline2.TT10 (Pin_10), board_outline2.TT12 (Pin_12), board_outline2.TT14 (Pin_14), board_outline2.TT16 (Pin_16), board_outline2.TT18 (Pin_18), board_outline2.TT20 (Pin_20)
GPIGPI1: D1.4, board_outline1.43 (GPI1), board_outline2.20 (I1)
GPIO1: D1.1, board_outline1.40 (GPIO1), board_outline2.14 (IO1)
GPIO2: D1.2, board_outline1.41 (GPIO2), board_outline2.16 (IO2)
GPIO34: GPI1.2, U2.5 (VDET_1/GPIO34/ADC1_CH6), board_outline2.28 (34)
GPIO35: GPI1.1, U2.6 (VDET_2/GPIO35/ADC1_CH7), board_outline2.26 (35)
GPO1: D1.3, board_outline1.42 (GPO1), board_outline2.18 (O1)
HOST_5V: C1.1, C33.1, U1.55 (5V), USBA1.1 (VBUS), USB_HOST_1.1 (5V)
HOST_D1+: U1.57 (D+), USBA1.3 (D+), USB_HOST_1.3 (D1+)
HOST_D1-: U1.56 (D-), USBA1.2 (D-), USB_HOST_1.2 (D1-)
IRQ: ILI1.14 (T_IRQ), ILI_LED2.2 (C), board_outline2.41 (Q)
LED: ILI1.8 (LED_(3.3V)), ILI_LED1.2 (C), board_outline2.29 (LED)
LRCK1: R9.2, U5.2 (1A), U5.5 (2A)
LRCK1+TDM1: R42.2, TDM1.13 (LRCK), board_outline1.13 (LRCK), board_outline2.T13 (LRCK)
LRCK1+TDM2: R43.2, TDM2.13 (LRCK), board_outline2.TT13 (Pin_13)
MCLK1: R7.2, U6.2 (1A), U6.5 (2A)
MCLK1+TDM1: R41.2, TDM1.19 (MCLK), board_outline1.19 (MCLK), board_outline2.T19 (MCLK)
MCLK1+TDM2: R40.2, TDM2.19 (MCLK), board_outline2.TT19 (Pin_19)
MCLK2: J19.1, R10.2
MIDI_IN_4: J17.1, MIDI_IN_1.2, R32.1, board_outline2.1 (I4)
MIDI_IN_5: D2.2 (A), J17.2, MIDI_IN_1.5, U4.2, board_outline2.2 (I5)
MIDI_OUT_4: J17.3, R39.1, board_outline2.3 (O4)
MIDI_OUT_5: J17.4, R38.1, board_outline2.4 (O5)
MIDI_RX: R34.1, U1.2 (0_RX1_CRX2_CS1), U4.4, U9.3
MIDI_THRU_4: J17.5, R37.1, board_outline2.5 (T4)
MIDI_THRU_5: J17.6, R36.1, board_outline2.6 (T5)
MIDI_TX_T: U1.3 (1_TX1_CTX2_MISO1), U9.1
unnamed: C7.2, J1.2, J_PHONE1.R
unnamed: C9.2, J3.1, J_PHONE1.T
unnamed: C16.2, R31.1, R34.2, U4.6
unnamed: CC1.2, U10.10 (NC)
unnamed: CC2.2, U10.6 (NC)
unnamed: D2.1 (K), R32.2, U4.1
unnamed: HPTRS1.2, J1.1, J5.2, J_PHONE1.RN
unnamed: HPTRS1.3, J5.1, R25.2
unnamed: HPTRS1.4, J4.2, R26.2
unnamed: HPTRS1.5, J3.2, J4.1, J_PHONE1.TN
unnamed: HPTRS2.3, J7.1, J9.T1
unnamed: HPTRS2.4, J6.2, J9.T2
unnamed: ILI_LED1.1 (A), R24.2
unnamed: J8.T1, R25.1
unnamed: J8.T2, R26.1
unnamed: J10.1, Q1.2 (S)
unnamed: C31.1, C32.1, J11.1, Q2.2 (S)
unnamed: PU_EN108.2, R20.1, R21.1
unnamed: PWR1.2 (A), RLED1.1
unnamed: PWR2.2 (A), RLED2.1
unnamed: PWR3.2 (A), RLED3.1
unnamed: R12.1, R13.2, R14.2
unnamed: R15.1, R16.2, R17.2
unnamed: R33.2, U4.5
unnamed: R36.2, U9.4
unnamed: R38.2, U9.6
unnamed: R48.2, board_outline2.B1
unnamed: R49.2, board_outline2.B3
unnamed: R50.2, board_outline2.B2
unnamed: R51.2, board_outline2.B4
unnamed: R1.2, U1.5 (3_LRCLK2)
unnamed: R2.1, U1.6 (4_BCLK2)
unnamed: R4.1, U1.8 (6_OUT1D)
unnamed: R3.1, U1.9 (7_RX2_OUT1A)
unnamed: R9.1, U1.42 (20_A6_TX5_LRCLK1)
unnamed: R6.1, U1.43 (21_A7_RX5_BCLK1)
unnamed: R7.1, U1.45 (23_A9_CRX1_MCLK1)
unnamed: R52.1, U1.23 (31_CTX3)
unnamed: R5.2, U1.24 (32_OUT1B)
unnamed: R10.1, U1.25 (33_MCLK2)
unnamed: R8.2, U1.33 (41_A17)
unnamed: R18.1, U2.29 (*GPIO5)
unnamed: R28.1, R29.2, U3.4 (PR1)
unnamed: R30.1, U3.8 (ST)
unnamed: R42.1, U5.6 (1Y)
unnamed: R43.1, U5.3 (2Y)
unnamed: R41.1, U6.6 (1Y)
unnamed: R40.1, U6.3 (2Y)
unnamed: R44.1, U7.6 (1Y)
unnamed: R45.1, U7.3 (2Y)
unnamed: R46.1, U8.6 (1Y)
unnamed: R47.1, U8.3 (2Y)
unnamed: C21.2, R35.1, U9.5 (VCC)
unnamed: U10.1 (IO1), USBC1.A5 (CC1)
unnamed: U10.2 (IO2), USBC1.A6 (DP1), USBC1.B6 (DP2)
unnamed: U10.4 (IO3), USBC1.A7 (DN1), USBC1.B7 (DN2)
unnamed: U10.5 (IO4), USBC1.B5 (CC2)
unnamed: J21.2, board_outline1.31 (IN1M)
OUTPUTA: ESP_R_ENC1.1, U1.32 (40_A16), U2.3 (SENSOR_VP/GPIO36/ADC1_CH0), board_outline2.34 (A36)
OUTPUTB: ESP_R_ENC1.2, U1.31 (39_MISO1_OUT1A), U2.4 (SENSOR_VN/GPIO39/ADC1_CH3), board_outline2.36 (B39)
RESET: ILI1.4 (RESET), U2.26 (ADC2_CH0/GPIO4), board_outline2.21 (RS)
SCK: ILI1.7 (SCK), ILI1.10 (T_CLK(SCK)), U2.30 (GPIO18), board_outline2.27 (SCK), board_outline2.33 (CK)
SCL0: R13.1, TDM1.17 (SCL), U1.41 (19_A5_SCL), board_outline1.17 (SCL), board_outline2.T17 (SCL)
SCL1: R17.1, TDM2.17 (SCL), U1.38 (16_A2_RX4_SCL1), board_outline2.TT17 (Pin_17)
SDA0: R14.1, TDM1.15 (SDA), U1.40 (18_A4_SDA), board_outline1.15 (SDA), board_outline2.T15 (SDA)
SDA1: R16.1, TDM2.15 (SDA), U1.39 (17_A3_TX4_SDA1), board_outline2.TT15 (Pin_15)
SDI: ILI1.6 (SDI(MOSI)), ILI1.12 (T_DIN(MOSI)), U2.37 (GPIO23), board_outline2.25 (DI), board_outline2.37 (DI)
SDO: ILI1.9 (SDO(MISO)), ILI1.13 (T_DO(MISO)), U2.31 (GPIO19), board_outline2.31 (X), board_outline2.39 (DO)
SWITCH: ESP_R_ENC1.3, U1.30 (38_CS1_IN1), U2.11 (ADC2_CH7/GPIO27), board_outline2.38 (S27)
TEENSY_LED: IC1.5 (2A), R8.1
TEENSY_LED+: D3.1 (DIN), IC1.3 (2Y)
TEENSY_LED_OUT: D3.3 (DOUT), J12.2, board_outline2.46 (TSY)
TRX3: J13.2, R52.2, board_outline2.53 (?)
T_BUTTON1: J16.1, U1.16 (24_A10_TX6_SCL2), board_outline2.52 (?)
T_BUTTON2: J16.2, U1.17 (25_A11_RX6_SDA2), board_outline2.54 (?)
T_CS: ILI1.11 (T_CS), R23.2, U2.7 (32K_XP/GPIO32/ADC1_CH4), board_outline2.35 (CS)
USB_SHIELD: G2.2, USBC1.S1 (SHELL), USBC1.S2 (SHELL), USBC1.S3 (SHELL), USBC1.S4 (SHELL), USB_DEVICE_1.5 (SHIELD)
USB_SHIELD2: G1.2, USBA1.5 (Shield), USB_HOST_1.5 (SHIELD)
VIN2_SECONDARY: C13.1, C14.1, J20.1, R27.1, U3.6 (VIN2)
V_BAT: BAT1.1, U1.50 (VBAT), board_outline2.61 (BAT)

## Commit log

2025-04-06 added tft touchscreen
    [TFT_320x240_touch_r0.step, audio_back_plane_35_rca.kicad_pcb, audio_back_plane_35_rca.kicad_sch]
2025-04-08 added touchscreen
    [audio_back_plane_35_rca.kicad_sch]
2026-02-07 Rename project to t-dsp_desktop_pro, add LICENSE and README
    Rename all project files, internal references, gerbers, and BOM from
    audio_back_plane_35_rca to t-dsp_desktop_pro. Add CC BY-NC-SA 4.0
    license and README modeled after the TAC5212 module repo. Update
    .gitignore to match t-dsp standards.
    [audio_back_plane_35_rca-B_Cu.gbr, audio_back_plane_35_rca-B_Mask.gbr, audio_back_plane_35_rca-B_Paste.gbr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]
2026-02-07 Clean up repo for public release
    Move snapshot archives, SolidWorks bundles, duplicate 3D models, and
    old enclosure assembly files to 3d_models/_unused/. Move third-party
    datasheets from lib_docs/ to documentation/_reference/. Remove lib_dl/
    (raw component library downloads) from tracking. All directories are
    gitignored to keep them local. Matches the t-dsp_tac5212 repo structure.
    [2.54 mm DUPONT MALE PIN HEADER, IO, 2X20, RPi4ModelB.SLDPRT, 2.54 mm DUPONT MALE PIN HEADER, IO, 2X40, RPi4ModelB.SLDPRT, 2.54 mm DUPONT MALE PIN HEADER, POE, 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]
2026-02-07 Add board images, schematic PDF, and update README
    Add 3D renders (top, bottom, front angle, back angle), PCB layout
    screenshot, and schematic PDF to documentation/. Update README with
    inline images and corrected project files table.
2026-02-07 Show all 4 board images together at top of README
2026-02-07 Clarify USB-C/USB-B are shared footprint options
2026-02-07 Update README: add on-board ICs table, refine processing and board design sections
    Add IC reference table (Teensy, ESP32, TPS2116, H11L1, bus buffers,
    Schmitt triggers). Update Processing to clarify ESP32 runs UI and
    Teensy handles audio/USB Audio. Remove TVS/ferrite references from
    Board Design (those are on the TAC5212 module, not the backplane).
2026-02-07 Rewrite connectivity and UI sections with accurate hardware details
    Fix audio I/O: RCA in/out, dual headphone jack options, MIDI input
    with GPIO for in/out/thru. Add dual power, SD card, and USB power/audio.
    Update UI section: GPIO header for flexible connectivity, LEDs for
    both ESP32 and Teensy.
2026-02-08 Add 3D STL export and KiCanvas viewer links to README
2026-02-11 Add KiBot CI pipeline, bundle 3D models locally, fix Blender renders
    - Add .kibot.yaml with full manufacturing outputs (gerbers, BOM, 3D renders)
    - Add GitHub Actions workflow for automated manufacturing file generation
    - Bundle ~26 standard KiCad library 3D models into 3d_models/ so they
    resolve in Docker/CI without a KiCad installation
    - Rewrite all PCB model paths from ${KISYS3DMOD}/${KICAD*_3DMODEL_DIR}
    to ${KIPRJMOD}/3d_models/ for portable resolution
    - Fix broken model refs (hardcoded Windows path, bare filename)
    - Set kicad_dnp_applies_to_3D: false so DNP-flagged schematic symbols
    (used for BOM filtering) keep their 3D models in Blender renders
    - Add local Docker test script (sc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
    [CP_Radial_D10.0mm_P5.00mm.step, C_1206_3216Metric.step, D_1210_3225Metric.step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]
2026-02-11 Clean up local artifacts and update .gitignore
    Add ignore rules for .claude/, ibom.config.ini, *.kicad_pro-bak, and
    nul. Remove .claude/settings.local.json from tracking.
2026-02-19 created expansion board outline with headers
    [t-dsp_desktop_pro.kicad_pcb, t-dsp_desktop_pro.kicad_sch]
2026-02-20 Localize all 3D model paths for Docker/CI rendering
    Rewrite all 3D model references from system variables (KICAD9_3DMODEL_DIR,
    KISYS3DMOD, KICAD6/8_3DMODEL_DIR) to ${KIPRJMOD}/3d_models/ so models
    resolve correctly in Docker-based KiBot CI builds. Copy 45 standard KiCad
    3D models to the project. Fix BOM field mismatches for RLED1/RLED2 and
    R36/R39 grouping. Update schematic symbol library and footprint libraries.
    [H11L1SM.step, JST_EH_S2B-EH_1x02_P2.50mm_Horizontal.step, LED_D5.0mm_Clear.step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]
2026-02-23 v0.8: Pre-production review - USB ESD, reverse polarity, boot pin fixes
    - Add USB-C ESD protection: TPD4E02B04 (D+/D-/CC1/CC2) + TPD1E10B06 (VBUS)
    - Add P-FET reverse polarity protection: DMG2307L-7 on 5V and 12V inputs
    - Fix USB-C reversibility: tie DP1+DP2 and DN1+DN2 together
    - Add ESP32 GPIO12 pull-down (10k) for 3.3V flash boot
    - Add ESP32 GPIO17 CS pull-up (10k)
    - Change SPI CS pull-ups R19/R22/R23 from 2.21k to 10k
    - Add 12V LED power indicator (PWR3 + RLED3 6.8k)
    - Change 5V LED resistors RLED1/RLED2 to 1k
    - Add 3D models and footprints for new components
    - Remove old gerbers directory (manufacturing outputs now via CI/CD)
    - 8-layer PCB layout with full LCSC codes for JLCPCB assembly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
    [DMG2307L-7.stp, LED_1210_3225Metric.step, SI2301CDS-T1-BE3.stp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]
2026-02-23 v0.81: Fix CI release, localize 3D models, update README with render gallery
    - Fix workflow: add gh release create before upload (tag != release)
    - Fix ZIP filename: remove empty %r board revision from output name
    - Localize 3D model paths for U10, C15, JST connectors to ${KIPRJMOD}
    - Add project-local footprints for C_1206 and JST_XH_S2B-XH-A
    - Trim SMD 3D renders from 8 to 4 views (top, bottom, top_iso, bottom_iso)
    - Update gallery.html to handle different view counts per set
    - Update README: Blender render thumbnails linking to gallery, fix IC table,
    add new components (U10, IC1, D5, Q1/Q2), update project files table
    [t-dsp_desktop_pro.kicad_pcb, t-dsp_desktop_pro.kicad_sch]
2026-02-24 v0.82: Fix audio output pin mapping and add PTC fuse footprint
    - Correct L/R channel assignment: Left=OUT1, Right=OUT2
    - Fix tip/ring polarity: +=tip, -=ring
    - Add PTC resettable fuse (MF-LSMF300) footprint and 3D model
    - Update workflow to include tag in manufacturing ZIP filename
    [MF-LSMF300_24X-2.stp, t-dsp_desktop_pro.kicad_pcb, t-dsp_desktop_pro.kicad_sch]
2026-02-24 v0.8.4: Production release - final layout and schematic updates
    [t-dsp_desktop_pro.kicad_pcb, t-dsp_desktop_pro.kicad_sch]

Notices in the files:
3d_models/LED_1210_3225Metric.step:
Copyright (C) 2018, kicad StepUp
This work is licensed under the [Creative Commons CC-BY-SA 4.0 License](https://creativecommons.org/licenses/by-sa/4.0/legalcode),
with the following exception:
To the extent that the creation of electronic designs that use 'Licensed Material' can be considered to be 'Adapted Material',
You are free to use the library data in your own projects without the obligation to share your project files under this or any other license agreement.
